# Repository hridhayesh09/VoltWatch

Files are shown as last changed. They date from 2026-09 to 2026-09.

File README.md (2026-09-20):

Overview
VoltWatch is a custom-designed PCB system that monitors residential power quality in real time, detects voltage surges, and sends alerts before equipment damage occurs. Inspired by a personal experience where a thunderstorm surge destroyed a pair of speakers.

## Hardware
- ESP32 WROOM-32 microcontroller
- ZMPT101B AC voltage sensor
- Custom PCB designed in KiCad (in progress)

## Stack
- Firmware: Embedded C on ESP32 (PlatformIO)
- Backend: Python Flask + SQLite
- Alerts: Twilio SMS (coming soon)
- Dashboard: React (coming soon)
- ML: scikit-learn anomaly detection (coming soon)

## How It Works
The ESP32 reads voltage data from the ZMPT101B sensor 1000 times per second, calculates peak-to-peak values, detects surge events, and sends timestamped data to a Flask backend over WiFi for storage and analysis.

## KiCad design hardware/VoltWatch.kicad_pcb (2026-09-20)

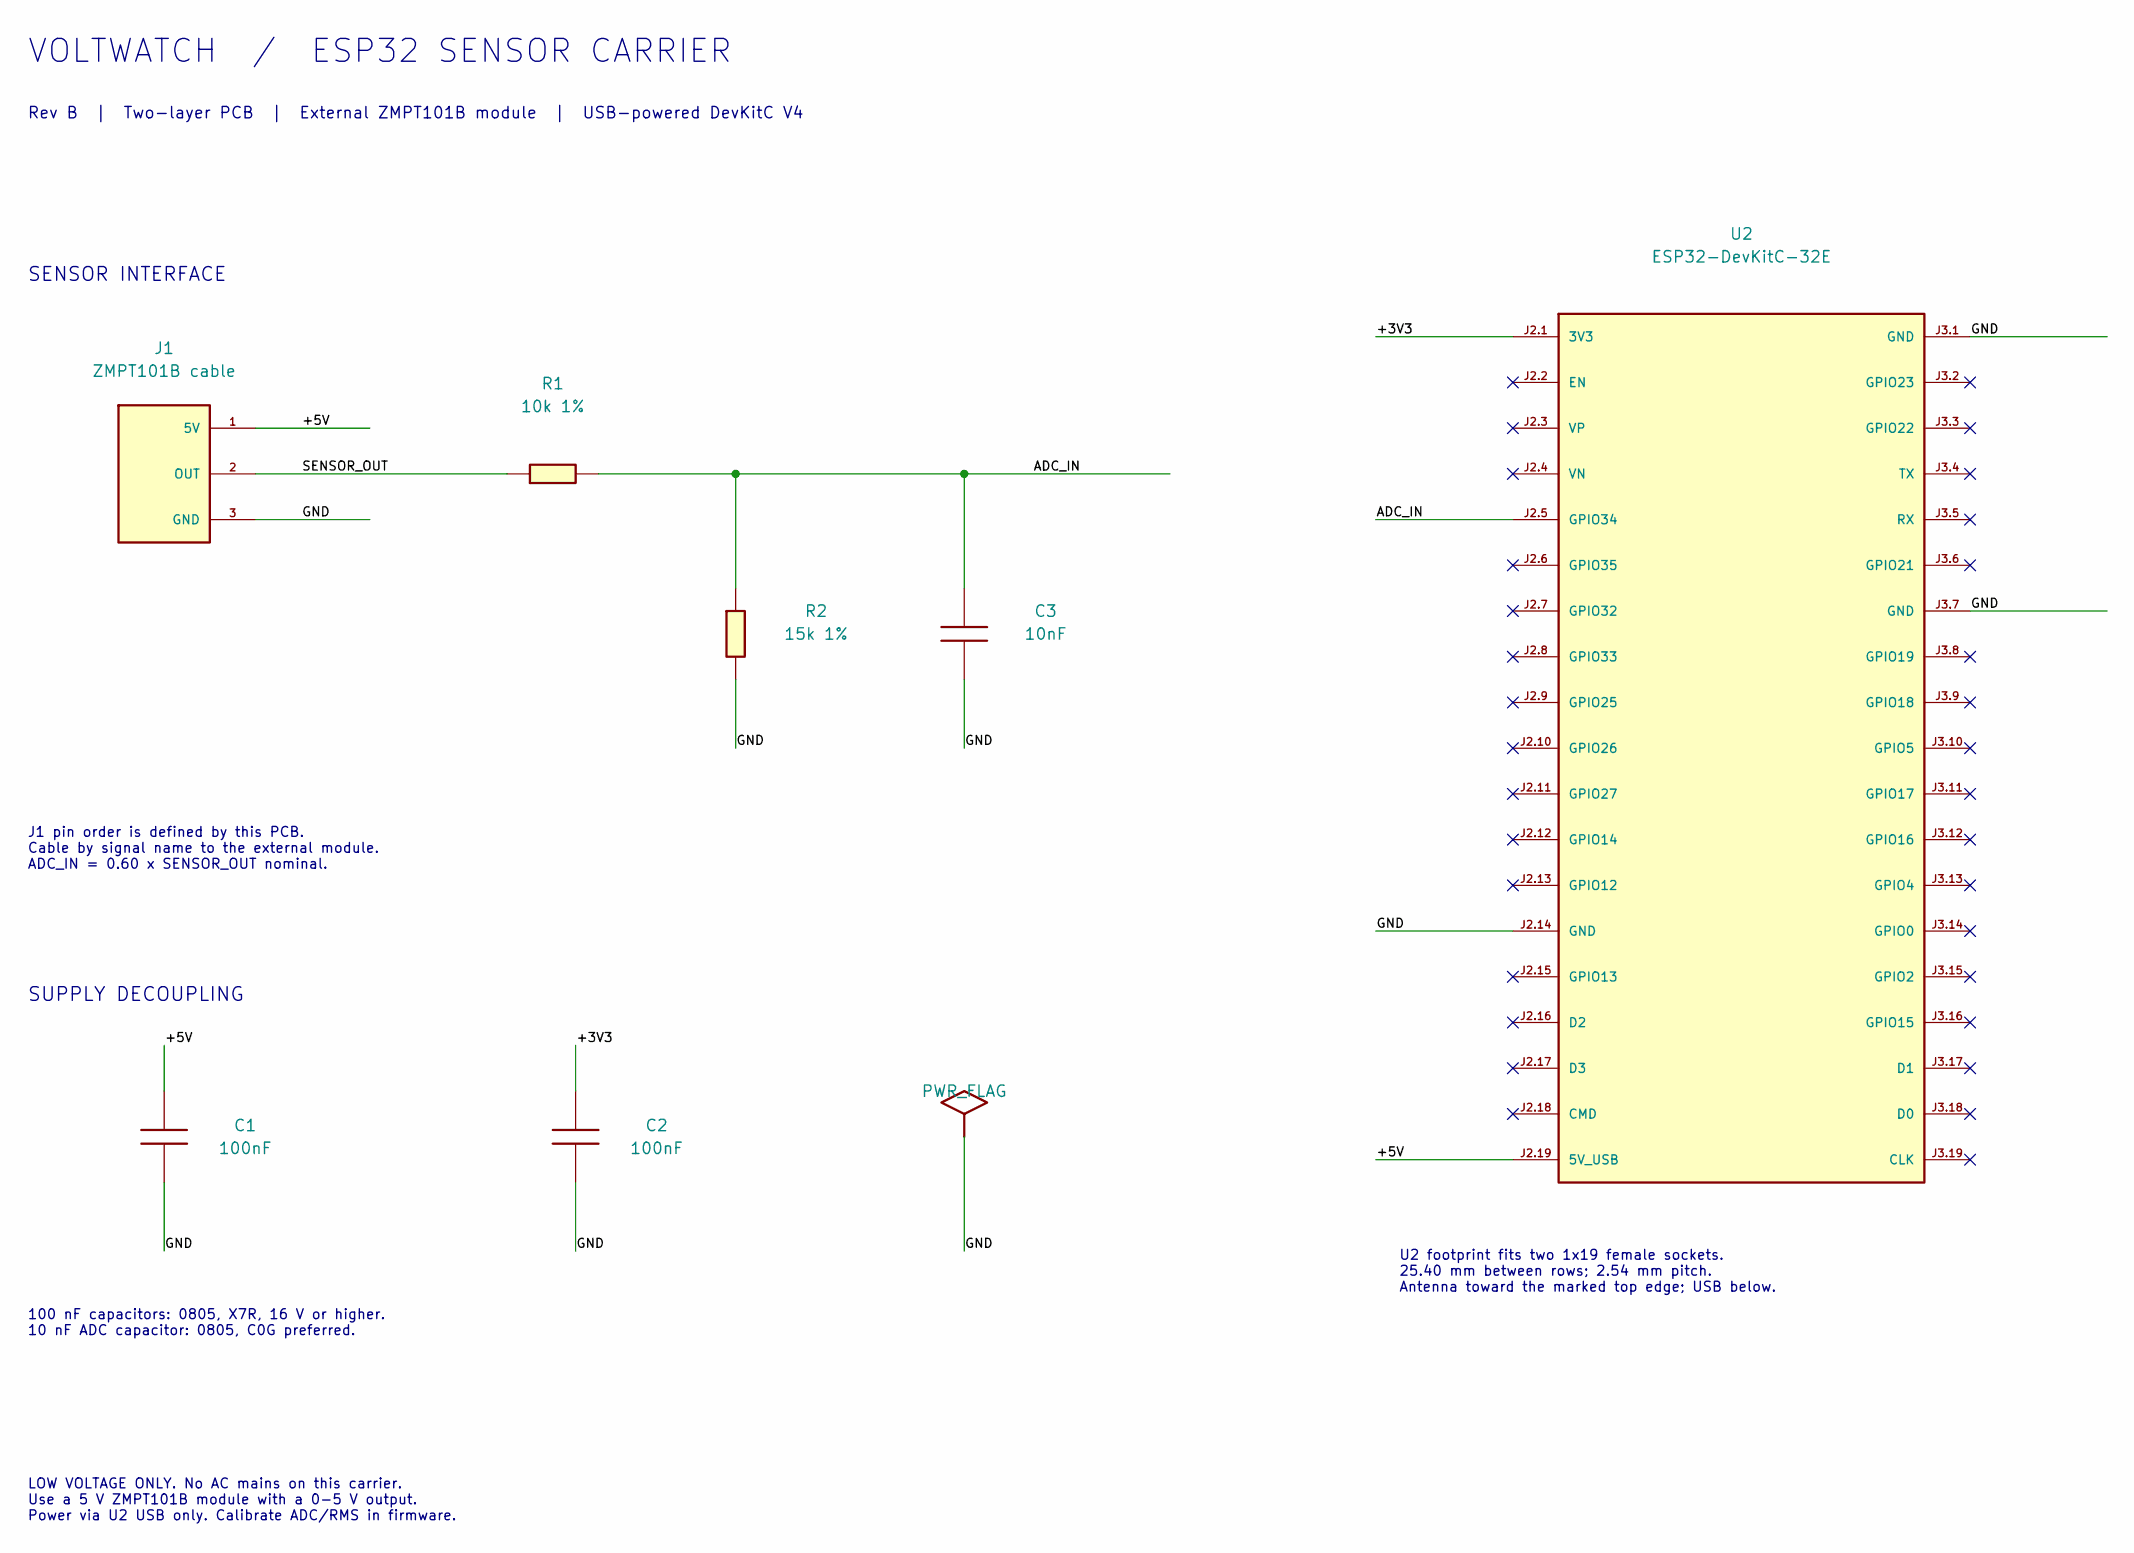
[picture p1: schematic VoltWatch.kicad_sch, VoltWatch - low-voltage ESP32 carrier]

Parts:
C1, C2: 100nF; C_0805_2012Metric
C3: 10nF; C_0805_2012Metric
J1: ZMPT101B cable; PinHeader_1x03_P2.54mm_Vertical
R1: 10k 1%; R_0805_2012Metric
R2: 15k 1%; R_0805_2012Metric
U2: ESP32-DevKitC-32E; ESP32_DevKitC_V4_Sockets

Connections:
/+3V3: C2.1, U2.J2.1 (3V3)
/+5V: C1.1, J1.1 (5V), U2.J2.19 (5V_USB)
/ADC_IN: C3.1, R1.2, R2.1, U2.J2.5 (GPIO34)
/GND: C1.2, C2.2, C3.2, J1.3 (GND), R2.2, U2.J2.14 (GND), U2.J3.1 (GND), U2.J3.7 (GND)
/SENSOR_OUT: J1.2 (OUT), R1.1

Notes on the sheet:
VOLTWATCH / ESP32 SENSOR CARRIER
Rev B | Two-layer PCB | External ZMPT101B module | USB-powered DevKitC V4
SENSOR INTERFACE
J1 pin order is defined by this PCB. Cable by signal name to the external module. ADC_IN = 0.60 x SENSOR_OUT nominal.
SUPPLY DECOUPLING
100 nF capacitors: 0805, X7R, 16 V or higher. 10 nF ADC capacitor: 0805, C0G preferred.
U2 footprint fits two 1x19 female sockets. 25.40 mm between rows; 2.54 mm pitch. Antenna toward the marked top edge; USB below.
LOW VOLTAGE ONLY. No AC mains on this carrier. Use a 5 V ZMPT101B module with a 0-5 V output. Power via U2 USB only. Calibrate ADC/RMS in firmware.

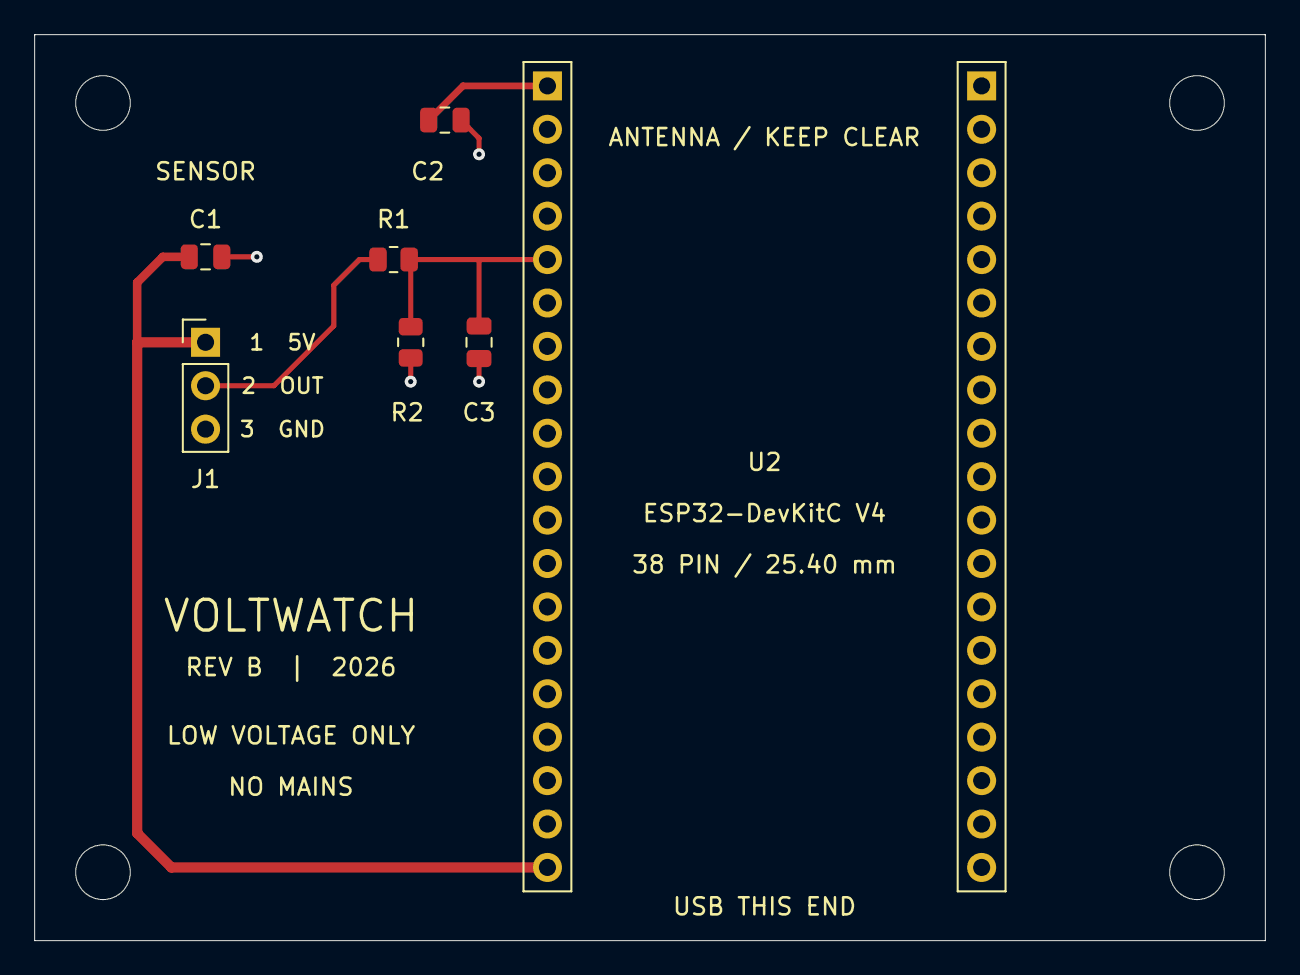
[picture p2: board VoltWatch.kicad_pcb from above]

Board: 2 copper layers, 72.0 x 53.0 mm, 11 parts (0 on the bottom side), 5 nets.

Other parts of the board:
H1, H2, H3, H4: M3; MountingHole_3.2mm_M3

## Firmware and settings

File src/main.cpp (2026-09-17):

#include <Arduino.h>
#include <WiFi.h>
#include <HTTPClient.h>

const char* ssid = "42-N-Resident";
const char* password = "SimplyExpertMood";
const char* serverURL = "http://172.16.22.218:5000/data";

#define ADC_PIN 34
#define SAMPLES 1000

void setup() {
  Serial.begin(115200);
  WiFi.begin(ssid, password);
  while (WiFi.status() != WL_CONNECTED) {
    delay(500);
    Serial.print(".");
  }
  Serial.println("WiFi Connected");
}

void loop() {
  long sum = 0;
  int maxVal = 0;
  int minVal = 4095;

  for(int i = 0; i < SAMPLES; i++) {
    int val = analogRead(ADC_PIN);
    sum += val;
    if(val > maxVal) maxVal = val;
    if(val < minVal) minVal = val;
    delayMicroseconds(100);
  }

  int average = sum / SAMPLES;
  int peakToPeak = maxVal - minVal;

  Serial.print("Peak to Peak: ");
  Serial.println(peakToPeak);
  if(peakToPeak > 200) {
  Serial.println("SURGE DETECTED!");
}
  if(WiFi.status() == WL_CONNECTED) {
    HTTPClient http;
    http.begin(serverURL);
    http.addHeader("Content-Type", "application/json");
    String payload = "{\"average\":" + String(average) + 
                 ",\"peak_to_peak\":" + String(peakToPeak) + 
                 ",\"surge\":" + String(peakToPeak > 200 ? 1 : 0) + "}";
    http.POST(payload);
    http.end();
  }

  delay(1000);
}

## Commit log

2026-09-17 Initial commit - working ESP32 firmware and Flask backend
2026-09-20 Add KiCad schematic, PCB layout and Gerber files
    [VoltWatch-B_Cu.gbr, VoltWatch-B_Mask.gbr, VoltWatch-B_Paste.gbr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]
